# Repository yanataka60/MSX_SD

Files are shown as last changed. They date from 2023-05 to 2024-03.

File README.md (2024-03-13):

# MSXにSD-CARDからロード、セーブ機能

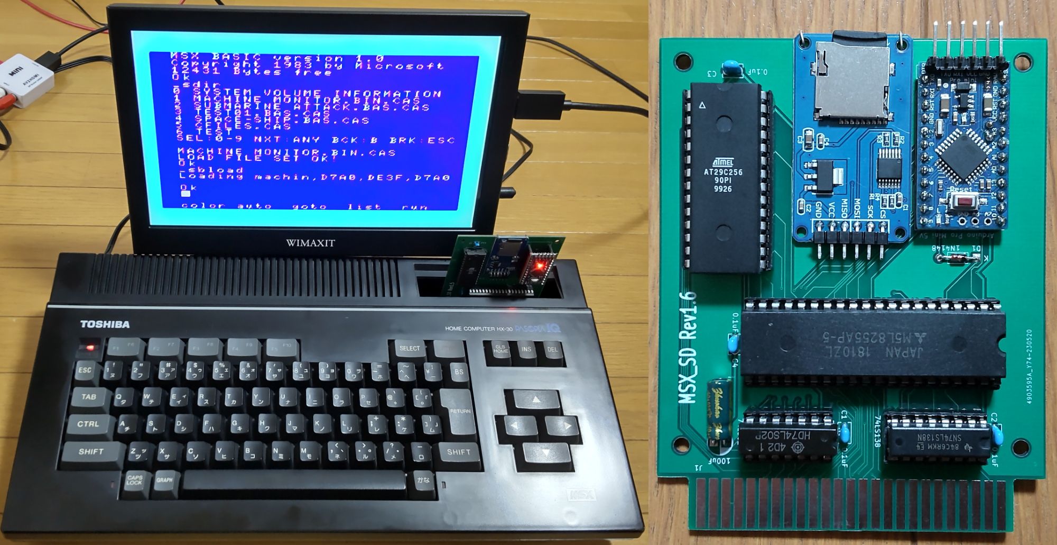
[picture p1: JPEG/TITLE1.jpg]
TITLE

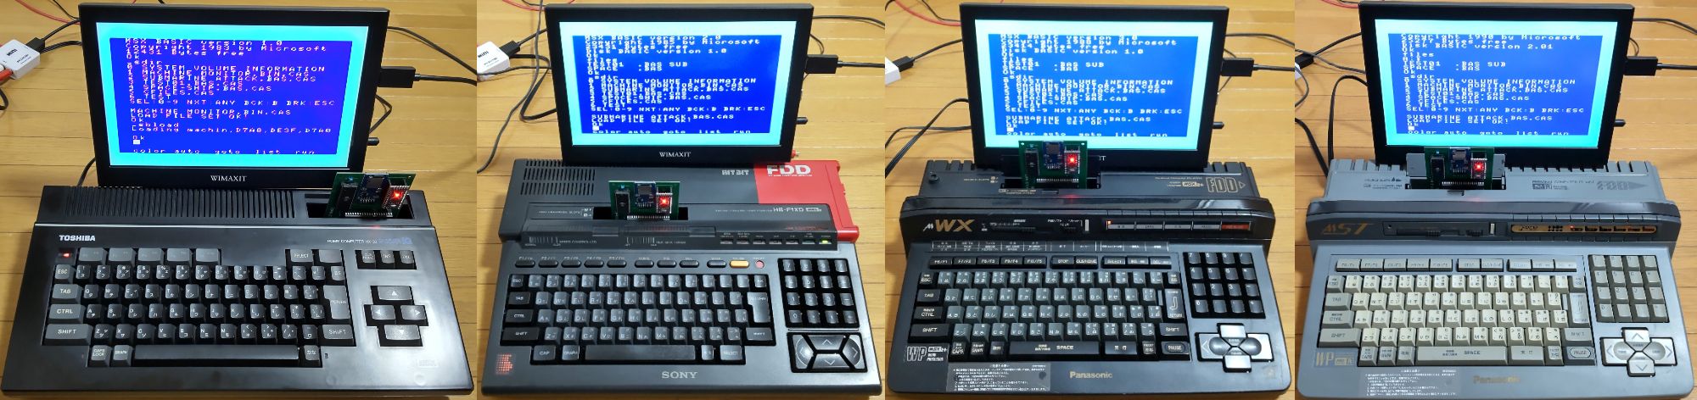
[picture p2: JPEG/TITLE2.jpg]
TITLE2


　MSX、MSX2、MSX2+、MSXturboRでSD-CARDからロード、セーブ機能を実現するものです。

　ROM-BASIC、DISK-BASICのどちらからも使えますが、DISK-BASICのフリーエリアでは動かないカセット用プログラム(ゲーム)もあります。

　FDD内蔵機種でフリーエリアが足りない場合は、SHIFTキーを押しながら電源投入又はリセットしてFDDを切り離してください。

　CMTからの読み込み実行に数分掛かっていたゲームも数十秒で実行できます。

　なお、Arduino、ROMへ書き込むための機器が別途必要となります。

## 対応できないもの
　BASICにSD専用命令を追加することでSD-CARDへのアクセスを実現しています。

　機械語からBIOSをコール、又は独自ルーチンでCMTからLOADするソフトには対応していません。

　雑誌打ち込み系のLOAD、SAVEを想定しています。市販ソフトはLOAD出来ればラッキーくらいに思って活用してください。

## 参考
　市販ソフトをcasファイル化した時に多段ロードではない単純にBASICプログラム、機械語プログラムをロードするものは大丈夫だと思います。

　また、２段ロードでも最初のBASICプログラム中から2段目の機械語プログラムを「BLOAD」で呼び出すものは「CALL SBLOAD」又は「CALL SBLOAD(,R)」に置き換えることで対応できると思います。

## 回路図
　KiCadフォルダ内のMSX_SD.pdfを参照してください。

[回路図](https://github.com/yanataka60/MSX_SD/blob/main/Kicad/MSX_SD.pdf)

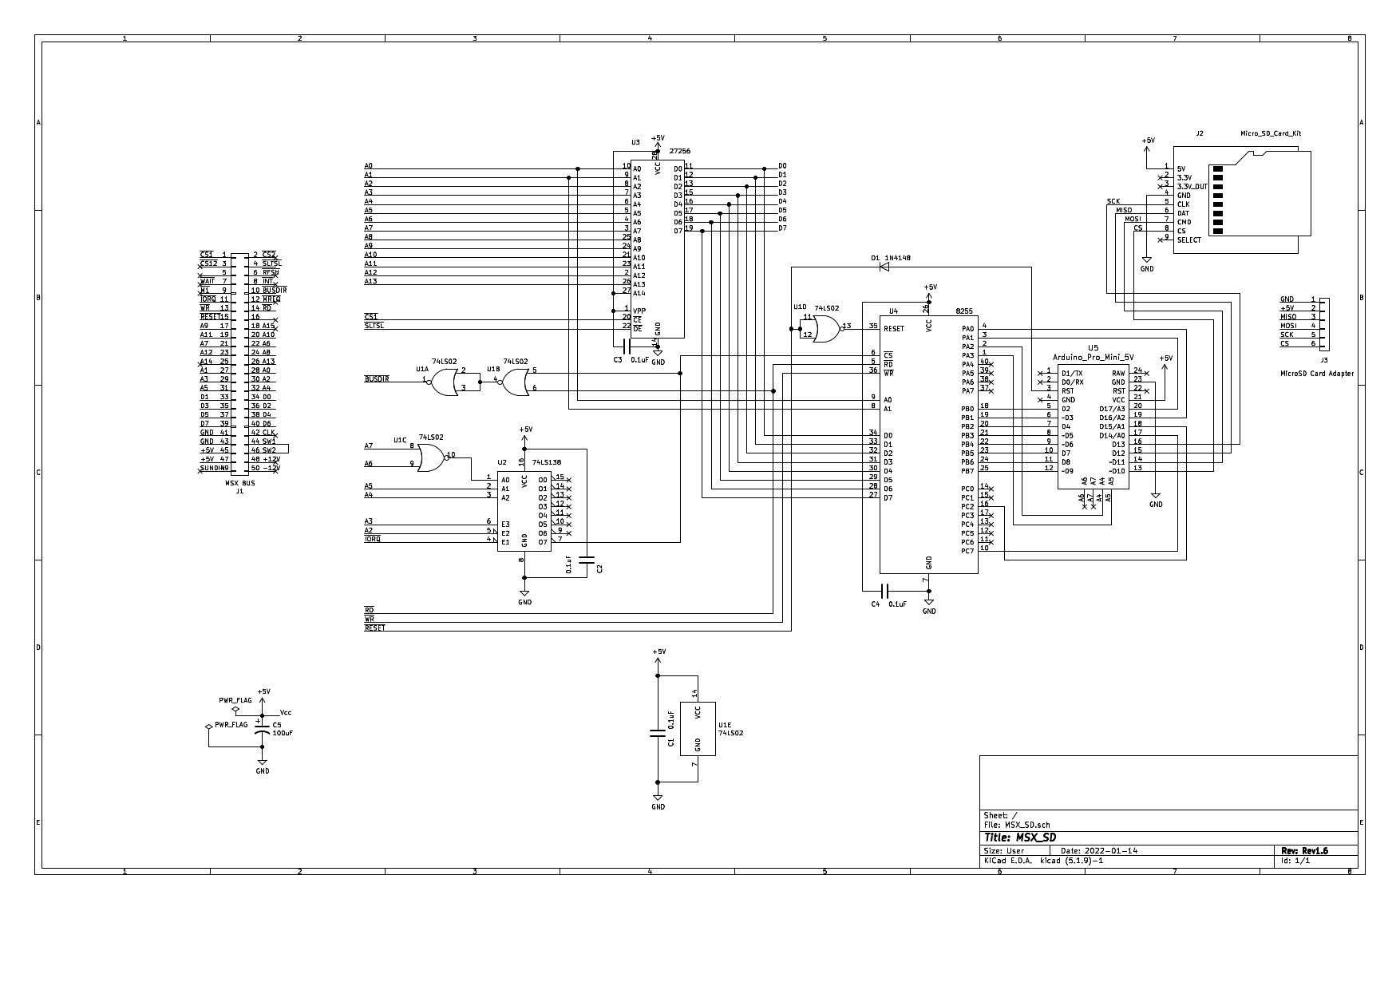
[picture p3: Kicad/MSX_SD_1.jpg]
MSX_SD


## 部品
|番号|品名|数量|備考|
| --- | --- | --- | --- |
||J2、J3のいずれか(注1)|||
|J2|Micro_SD_Card_Kit|1|秋月電子通商 AE-microSD-LLCNV (注2)|
|J3|MicroSD Card Adapter|1|Arduino等に使われる5V電源に対応したもの (注4)|
|D1|1N4148|1||
|U1|74LS02|1||
|U2|74LS138|1||
|U3|27256相当品|1|29C256は可、28C256は不可|
|U4|8255|1||
|U5|Arduino_Pro_Mini_5V|1|Atmega328版を使用 168版は不可。(注3)|
|C1～C4|積層セラミックコンデンサ 0.1uF|4||
|C5|電解コンデンサ 16v100uF|1||
||ピンヘッダ|2Pin分|Arduino_Pro_MiniにはA4、A5用のピンヘッダが付いていないため別途調達が必要です 秋月電子通商 PH-1x40SGなど|
||ピンソケット(任意)|26Pin分|Arduino_Pro_Miniを取り外し可能としたい場合に調達します 秋月電子通商 FHU-1x42SGなど|

　　　注1)J2又はJ3のどちらかを選択して取り付けてください。

　　　注2)秋月電子通商　AE-microSD-LLCNVのJ1ジャンパはショートしてください。

　　　注3)Arduino Pro MiniはA4、A5ピンも使っています。

　　　注4)MicroSD Card Adapterを使う場合

　　　　　J3に取り付けます。

　　　　　MicroSD Card Adapterについているピンヘッダを除去してハンダ付けするのが一番確実ですが、J3の穴にMicroSD Card Adapterをぴったりと押しつけ、裏から多めにハンダを流し込むことでハンダ付けをする方法もあります。なお、この方法の時にはしっかりハンダ付けが出来たかテスターで導通を確認しておいた方が安心です。

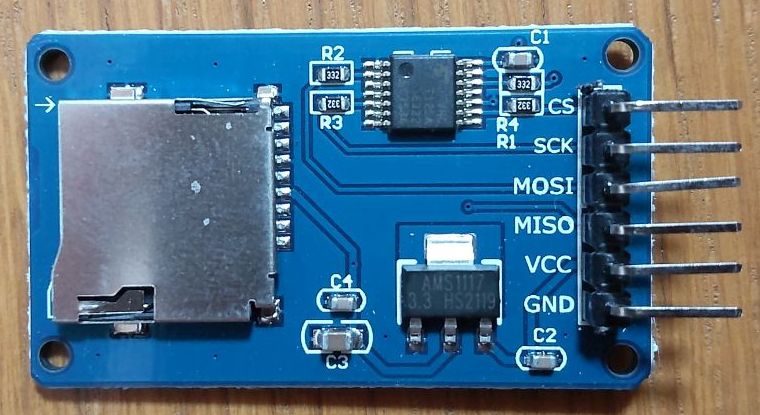
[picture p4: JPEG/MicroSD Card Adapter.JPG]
MicroSD Card Adapter1


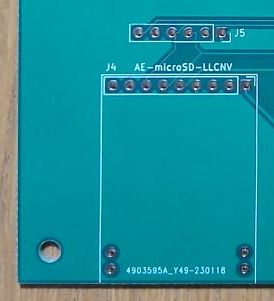
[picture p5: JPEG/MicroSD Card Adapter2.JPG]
MicroSD Card Adapter2


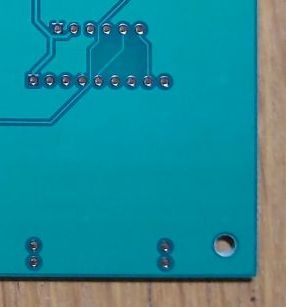
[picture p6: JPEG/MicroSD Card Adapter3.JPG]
MicroSD Card Adapter3


## ROMへの書込み
　Z80フォルダ内のEXT_ROM.binをROMライター(TL866II Plus等)を使って27256又は29C256に書き込みます。

## Arduinoプログラム
　Arduino IDEを使ってArduinoフォルダのMSX_SDフォルダ内MSX_SD.inoを書き込みます。

　SdFatライブラリを使用しているのでArduino IDEメニューのライブラリの管理からライブラリマネージャを立ち上げて「SdFat」をインストールしてください。

　「SdFat」で検索すれば見つかります。「SdFat」と「SdFat - Adafruit Fork」が見つかりますが「SdFat」のほうを使っています。

## 接続
　カートリッジスロットに挿入します。

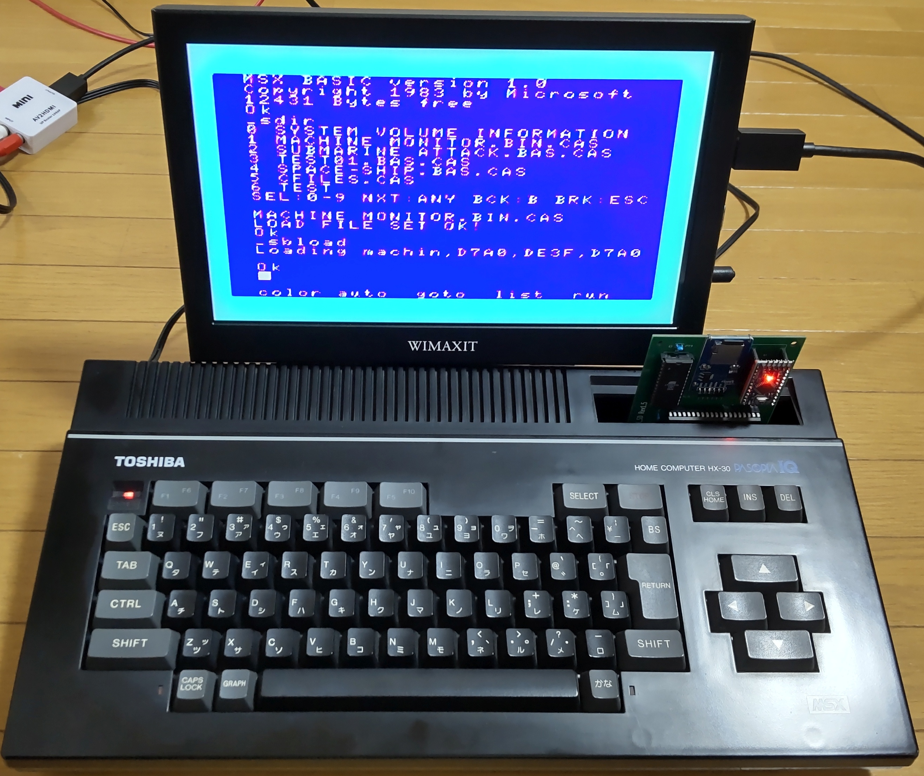
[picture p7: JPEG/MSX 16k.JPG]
cartridge


### SD-CARD
　出来れば8GB以下のSDカードを用意してください。

　ArduinoのSdFatライブラリは、SD規格(最大2GB)、SDHC規格(2GB～32GB)に対応していますが、SDXC規格(32GB～2TB)には対応していません。

　また、SDHC規格のSDカードであっても32GB、16GBは相性により動作しないものがあるようです。

　FAT16又はFAT32が認識できます。NTFSは認識できません。

　ルートに置かれた拡張子が「.CAS」形式ファイルのみ認識できます。(以外のファイル、フォルダも表示されますがLOAD実行の対象になりません)

　ファイル名は拡張子を除いて32文字まで、ただし半角カタカナ、及び一部の記号はArduinoが認識しないので使えません。パソコンでファイル名を付けるときはアルファベット、数字および空白でファイル名をつけてください。

## 使い方
　BASICから以下のコマンドが使えます。

　各コマンドでパラメータを指定する場合には必ず"("をつけてください。"("が無い場合には、MSXの仕様により入力した文字列のすべてがコマンド名として解釈されるため、パラメータを指定しなかったことになります。

### ○CALL SDIR[CR] 又は CALL SDIR("文字列")[CR]
### 【省略形】_SDIR[CR] 又は _SDIR("文字列")[CR]

文字列を指定するときは必ず"("をつけてください。後ろの")"は有っても無くても構いません。

ダブルコーテーションは有っても無くても構いません。

文字列を入力せずにSDIR[CR]のみ入力するとSD-CARDルートディレクトリにあるファイルの一覧を表示します。

文字列を付けて入力すればSD-CARDルートディレクトリにあるその文字列から始まるファイルの一覧を表示します。

10件表示したところで指示待ちになるので打ち切るならESCを入力すると打ち切られ、Bキーで前の10件に戻ります。それ以外のキーで次の10件を表示します。

　行頭に0から9の数字を付加して表示してあるのでSETLしたいファイルの頭についている数字を入力するとSETLコマンドが実行されます。

　表示される順番は、登録順となりファイル名アルファベッド順などのソートした順で表示することはできません。

#### 例)
　　CALL SDIR[CR]

　　CALL SDIR("P")[CR]

　　CALL SDIR(P)[CR]

### ○CALL SETL("DOSファイル名")[CR]
### 【省略形】_SETL("DOSファイル名")[CR]
指定したDOSファイル名のファイルをSD-CARDからLOAD出来るようにセットします。ファイル名の前には必ず"("をつけてください。後ろの")"は有っても無くても構いません。

ダブルコーテーションは有っても無くても構いません。

ファイル名の最後の「.cas」は有っても無くても構いません。

SETLを実行することでカセットテープをセットして読み込む準備をしたことになります。

#### 例)
　　CALL SETL("TEST")[CR]

### ○CALL SLOAD[CR] 又は CALL SLOAD("ファイル名")[CR]
### 【省略形】_SLOAD[CR] 又は _SLOAD("ファイル名")[CR]
CALL SDIR又はCALL SETLでセットしたDOSファイル名に記録されているBASICプログラムをロードします。

ファイル名の前には必ず"("をつけてください。

ダブルコーテーションは有っても無くても構いません。

ファイルデスクリプタ「CAS0:」は不要です。

ASCII形式のBASICプログラムには対応していません。

Rオプションには対応していません。LOAD後実行したい場合にはマルチステートメントでRUNを付け加え、CALL SLOAD:RUN[CR]又はCALL SLOAD("ファイル名"):RUN[CR]などとしてください。

ファイル名が指定されていなければ最初に見つけたBASICプログラムから、ファイル名を指定していれば入力したファイル名から始まるBASICプログラムが見つかるとロードが始まります。

#### 例)
　　CALL SLOAD[CR]

　　CALL SLOAD("TEST")[CR]

カセットテープと同じようにSLOAD命令等で読み込みが行われる度にDOSファイル名で指定したファイルに保存されているプログラムが先頭から一つずつ読み込まれます。

カセットデッキのように巻き戻しは無いので戻りたい時にはもう一度CALL SDIR又はCALL SETLコマンドを実行すれば先頭のプログラム又はデータに戻ります。

### ○CALL SBLOAD[CR]、CALL SBLOAD ("ファイル名")[CR]、CALL SBLOAD(,R)[CR] 又は CALL SBLOAD ("ファイル名",R)[CR]
### 【省略形】_SBLOAD[CR]、_SBLOAD ("ファイル名")[CR]、_SBLOAD(,R)[CR] 又は _SBLOAD ("ファイル名",R)[CR]
CALL SDIR又はCALL SETLでセットしたDOSファイル名に記録されている機械語プログラムをロードします。

ファイル名の前には必ず"("をつけてください。

ダブルコーテーションは有っても無くても構いません。

ファイルデスクリプタ「CAS0:」は不要です。

RオプションをつけることでLOAD後指定された実行開始アドレスから直ちに実行されます。

ファイル名が指定されていなければ最初に見つけた機械語プログラムから、ファイル名を指定していれば入力したファイル名から始まる機械語プログラムが見つかるとロードが始まります。

#### 例)
　　CALL SBLOAD[CR]

　　CALL SBLOAD("TEST")[CR]

　　CALL SBLOAD(,R)[CR]

　　CALL SBLOAD("TEST",R)[CR]

カセットテープと同じようにSBLOAD命令等で読み込みが行われる度にDOSファイル名で指定したファイルに保存されているプログラムが先頭から一つずつ読み込まれます。

カセットデッキのように巻き戻しは無いので戻りたい時にはもう一度CALL SDIR又はCALL SETLコマンドを実行すれば先頭のプログラム又はデータに戻ります。

### ○CALL SETS("DOSファイル名")[CR]
### 【省略形】_SETS("DOSファイル名")[CR]
SD-CARDへのSAVEが指定したDOSファイル名のファイルとなるようにセットします。ファイル名の前には必ず"("をつけてください。後ろの")"は有っても無くても構いません。

ダブルコーテーションは有っても無くても構いません。

ファイル名の最後の「.cas」は有っても無くても構いません。

指定したDOSファイル名のファイルがSD-CARDに存在しない場合は新たに作成され、存在する場合にはそのファイルの続きに追記されます。

SETSを実行することでカセットテープをセットして書き込む準備をしたことになります。

なお、SETSを実行せずにSSAVE、SBSAVEコマンドを実行すると「DEFAULT.cas」というDOSファイル名のファイルに自動的に書き込まれます。

「DEFAULT.cas」でなく好きなDOSファイル名のファイルに書き込みたい時には事前にSETSコマンドを実行してください。

#### 例)
　　CALL SETS("TEST")[CR]

### ○CALL SSAVE("ファイル名")[CR]
### 【省略形】_SSAVE("ファイル名")[CR]
CALL SETSでセットしたDOSファイル名のファイルにBASICプログラムをSAVEします。

ファイル名の前には必ず"("をつけてください。

ダブルコーテーションで必ず括る必要はありませんが、MSXの仕様上ダブルコーテーションで括った場合には文字列として判断され小文字はそのまま小文字ですが、括らなかった場合には変数名と判断され小文字はすべて大文字に変換されます。

ファイルデスクリプタ「CAS0:」は不要です。

ファイル名は省略できません。6文字以内でファイル名を指定してください。

#### 例)
　　CALL SSAVE("test")[CR]　　　:ファイル名testとしてSAVEされます。

　　CALL SSAVE("TEST")[CR]　　　:ファイル名TESTとしてSAVEされます。

　　CALL SSAVE(test)[CR]　　　　:ファイル名TESTとしてSAVEされます。

　　CALL SSAVE(TEST)[CR]　　　　:ファイル名TESTとしてSAVEされます。

カセットテープと同じようにSSAVE命令等で書き込みが行われる度にDOSファイル名で指定したファイルにBASICプログラムを追記します。

### ○CALL SBSAVE("ファイル名",開始アドレス,終了アドレス,実行開始アドレス)[CR]
### 【省略形】_SBSAVE("ファイル名",開始アドレス,終了アドレス,実行開始アドレス)[CR]
CALL SETSでセットしたDOSファイル名のファイルに開始アドレスから終了アドレスまでのメモリ上に置かれている機械語プログラムをSAVEします。

ファイル名の前には必ず"("をつけてください。

ダブルコーテーションで必ず括る必要はありませんが、MSXの仕様上ダブルコーテーションで括った場合には文字列として判断され小文字はそのまま小文字ですが、括らなかった場合には変数名と判断され小文字はすべて大文字に変換されます。

ファイルデスクリプタ「CAS0:」は不要です。

ファイル名、開始アドレス、終了アドレス、実行開始アドレスは16進数(&H)または32767までの10進数で指定してください。省略できません。

6文字以内でファイル名を指定してください。

#### 例)
　　CALL SBSAVE("TEST",&HA000,&HAFFF,&HA000)[CR]

カセットテープと同じようにSBSAVE命令等で書き込みが行われる度にDOSファイル名で指定したファイルに機械語プログラムを追記します。

### ○CALL DUMP[CR] 又は CALL DUMP(開始アドレス)[CR]
### 【省略形】_DUMP[CR] 又は _DUMP(開始アドレス)[CR]
メモリの内容を開始アドレスから128Byte分表示します。

開始アドレスを指定する場合には"("をつけ、16進数(&H)または32767までの10進数で指定してください。

開始アドレスを省略した場合には直前にCALL SBLOADされた機械語プログラムの実行開始アドレス又はCALL DUMPで表示された続きを表示します。

#### 例)
　　CALL DUMP(&HA000)[CR]　　　:アドレスA000からメモリ内容を表示します。

　　直後にCALL DUMP[CR]　　　　:直前に表示したメモリ内容(&HA000～&HA07F)の続きとして&HA080～&HA0FFを表示します。

　　CALL SBLOADを実行した直後にCALL DUMP[CR]　　　　:直前にLOADされた機械語プログラムの実行開始アドレスからメモリ内容を表示します。

### ○CALL EDIT[CR] 又は CALL EDIT(開始アドレス)[CR]
### 【省略形】_EDIT[CR] 又は _EDIT(開始アドレス)[CR]
開始アドレスが表示されるのでその後ろに16進数を入力し最後に[CR]を押すことでメモリにデータを書き込むことができます。

開始アドレスを指定する場合には"("をつけ、16進数(&H)または32767までの10進数で指定してください。

開始アドレスを省略した場合には直前にCALL SBLOADされた機械語プログラムの実行開始アドレス又はCALL DUMPで表示された続きのアドレスが書き込み開始アドレスとなります。

#### 例)
　　CALL EDIT(&HA000)[CR]　　　:とすると改行してA000が表示されるので16進数を入力後[CR]を押す。

　　A000 12 34 56 78 90[CR]　　:アドレスA000から 12 34 56 78 90の5Byteが書き込まれ、次のアドレスA005が表示される。

　　A005 [CR]　　　　　　　　　:終了したい時はアドレス表示の後に[CR]だけ押せば終了となる。

### ○CALL GOTO[CR] 又は CALL GOTO(実行開始アドレス)[CR]
### 【省略形】_GOTO[CR] 又は _GOTO(実行開始アドレス)[CR]
実行開始アドレスの機械語プログラムを呼び出します。

開始アドレスを指定する場合には"("をつけ、16進数(&H)または32767までの10進数で指定してください。

開始アドレスを省略した場合には直前にCALL SBLOADされた機械語プログラムの実行開始アドレス又はCALL DUMPで表示された続きが実行開始アドレスとなります。

#### 例)
　　CALL GOTO(&HA000)[CR]　　　:アドレスA000からの機械語プログラムを呼び出します。

　　CALL SBLOADを実行した直後にCALL GOTO[CR]　　　:直前にLOADされた機械語プログラムの実行開始アドレスの機械語プログラムを呼び出します。CALL SBLOAD(,R)と同等の動作となります。

### 操作上の注意
　~~「SD-CARD INITIALIZE ERROR」と表示されたときは、SD-CARDが挿入されているか確認し、SD-CARDを挿入して再度実行してください。~~

　~~SD-CARDにアクセスしていない時に電源が入ったままで SD-CARDを抜いた後、再挿入しても動作します。もし、「SD-CARD INITIALIZE ERROR」となる場合には本体の電源を入れ直してください。~~

　(2024.3.13) SD-CARDにアクセスしていない時に電源が入ったままでSD-CARDを抜くと再度SD-CARDを挿入してもSD-CARDにアクセスできない問題を解消しました。(Arduinoを最新版に書き換えてください)

　再度SD-CARDを挿入した後、_SDIR、_SETL、_SETS、_SSAVE、_SBSAVE等でSD-CARDに3回ほどアクセスすれば復旧します。

　_SLOAD、_SBLOADでも復旧しますが、_SDIR、_SETL等DOSファイル名をセットするところから復旧させることをお勧めします。

## 機械語多段ロードでBIOSをコールしているプログラムへの対応【テストバージョン】
　「MSX快速マシン語ゲーム集」に掲載されている「ジグソーセット」は、選んだ絵のデータを機械語のサブプログラムからBIOSのCMTアクセスルーチンをコールしてロードする仕様になっています。

　CALL文で拡張したSDアクセス用のコマンドではBIOSを直接コールするアプリケーションには対応できないのでアプリケーション中のCMT用BIOSコール部分を書き換えてSDアクセスする実験をしてみました。

　今回は、BIOSのCMTロード関連のみパッチを当てています。BIOSのCMTセーブ関連は未対応です。

　同様に、機械語多段ロードでBIOSをコールしているゲーム等ももしかしたら起動できるかもしれません。

#### 注意
　アプリケーションからSDアクセスルーチンをコールするためにSDアクセスルーチンをFDのワークエリアにコピーしています。機械語多段ロードでBIOSをコールしているプログラムをテストするときは必ずFDを切り離して起動してください。

　機械語多段ロードでBIOSをコールしているプログラムをロード実行しない限りFDとは共存します。

　なお、機械語多段ロードのアプリケーションでもBIOSのCMT関連ルーチンをコールせず、独自の特殊フォーマットでCMTから読み込んでいるものは対処しようがないので読み込めません。

### ROMへの書込み
　BIOS CALL REPLACE TESTフォルダ内Z80フォルダ内のEXT_ROM.binをROMライター(TL866II Plus等)を使って27256又は29C256に書き込みます。

　同ファイルにあるEXT_ROM2.sはアセンブル後のコードをEXT_ROM.binに含めてあります。

　テスト用のプログラムを付け加えた以外は通常版と同じですのでテストを止めたとしても元に戻す必要はありません。

### Arduinoプログラム
　Arduino IDEを使ってBIOS CALL REPLACE TESTフォルダ内ArduinoフォルダのMSX_SDフォルダ内MSX_SD.inoを書き込みます。

　テスト用のプログラムを付け加えた以外は通常版と同じですのでテストを止めたとしても元に戻す必要はありません。

### アプリケーションパッチあてWindows用ツール
　デスクトップ等適当な場所にBIOS CALL REPLACE TESTフォルダ内の「CAS2SD_CHECK.exe」をコピーしてダブルクリックで起動させてください。

　次にSD用パッチを当てたいCASファイルをCAS2SD_CHECKにドラッグアンドドロップしてください。

　ドロップされたアプリケーションにBIOSのCMT関連ルーチンを呼び出していると思われるコードが発見された場合は、元のCASファイルと同じフォルダに元のCASファイルのファイルネームに「_SD」を付加したCASファイルと変更箇所を保存したTXTファイルを作成します。

　ドロップされたアプリケーションにBIOSのCMT関連ルーチンを呼び出していると思われるコードが無い場合には、何も作成されません。

例)

　「JIGSAW SET.cas」をドラッグアンドドロップ

　　JIGSAW SET_SD.cas、JIGSAW SET_SD.txtが作成される。

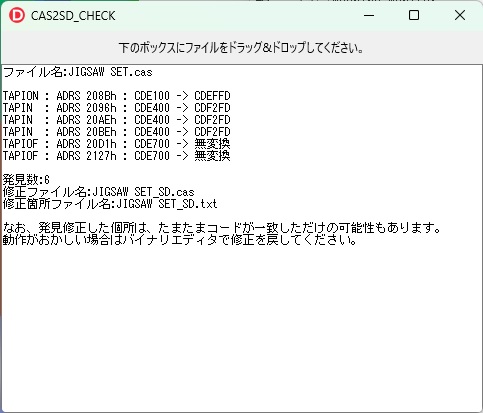
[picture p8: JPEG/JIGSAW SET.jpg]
JIGSAW SET


### レトロPC用ビットマップコンバーター TINY Bitmap Converterで生成された画像のロード
　TINY野郎さんのTINY Bitmap Converterで作られたCASファイルをMSX_SDで読み込むためのパッチ当てプログラムを作ってみました。

　デスクトップ等適当な場所にBIOS CALL REPLACE TESTフォルダ内の「TINYBMPCONV_MSX_SD_CONV.exe」をコピーしてダブルクリックで起動させてください。

　次にSD用パッチを当てたいCASファイルをTINYBMPCONV_MSX_SD_CONVにドラッグアンドドロップしてください。

　ドロップされた元のCASファイルと同じフォルダに元のCASファイルのファイルネームに「_SD」を付加したCASファイルを作成します。

　TINY Bitmap ConverterでMSX用に生成されたCASファイル以外をドロップしても多分何も作成されません。

例)

　「GAZOU.cas」をドラッグアンドドロップ

　　GAZOU_SD.casが作成される。

#### やっていること
　TINY Bitmap ConverterでMSX用に生成されたCASファイルはBASICで書かれたローダーの後ろに画像データがあります。

　BASICで書かれたローダーはDATA文で読み込んだ機械語をメモリに書き込んで実行していますが、DATA文なのでCAS2SD_CHECKを使ってもMSX_SD用にパッチ当てが出来ません。

　そこでDATA文に書かれたCMTルーチンコール用の機械語をSD用に置き換えています。

## 謝辞
　基板の作成に当たり以下のデータを使わせていただきました。ありがとうございます。

　Arduino Pro Mini

　　https://github.com/g200kg/kicad-lib-arduino

　AE-microSD-LLCNV

　　https://github.com/kuninet/PC-8001-SD-8kRAM

　にが様に多大なるご助言を頂きました。ありがとうございます。

## 追記
2023.5.22 キースキャンルーチンにWAITを追加

2023.5.28 _SBLOAD(,R)、_GOTOコマンドからのリターン時にHLレジスタを復帰していなかったバグを修正

　　　　_GOTOコマンドで実行開始アドレス省略時にマルチステートメントに対応していなかったバグを修正

　　　　マシン語自動実行用ワークエリア調整

2023.6.3 機械語多段ロードでBIOSをコールしているプログラムへの対応【テストバージョン】をアップした。

2023.8.2 ROMへの書込みにアドレス0000Hからで済むよう変更した。

2024.1.15 SDカードは8GB以下が望ましいことを追記。

2024.2.4 TINY Bitmap Converter用パッチ当てプログラムを作成。

2024.3.13 電源が入ったままでSD-CARDを抜くと再度SD-CARDを挿入してもSD-CARDにアクセスできない問題を解消した。

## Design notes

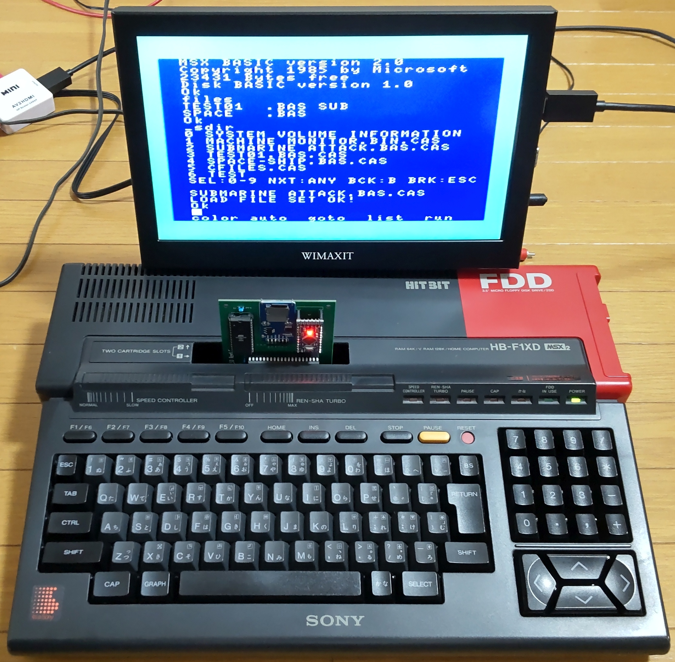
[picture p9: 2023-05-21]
JPEG/MSX2.JPG

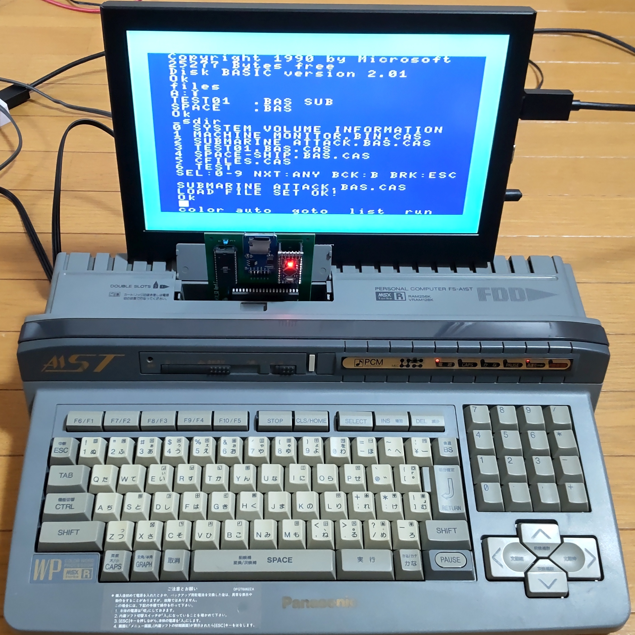
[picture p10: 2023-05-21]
JPEG/MSXturboR.JPG

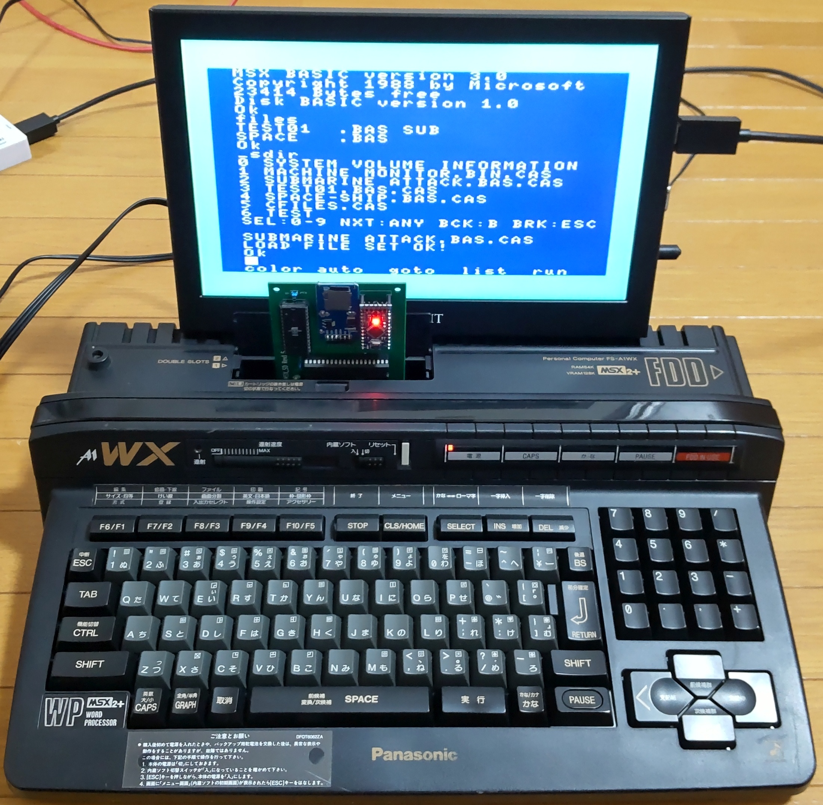
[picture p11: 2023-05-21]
JPEG/MSX2+.JPG

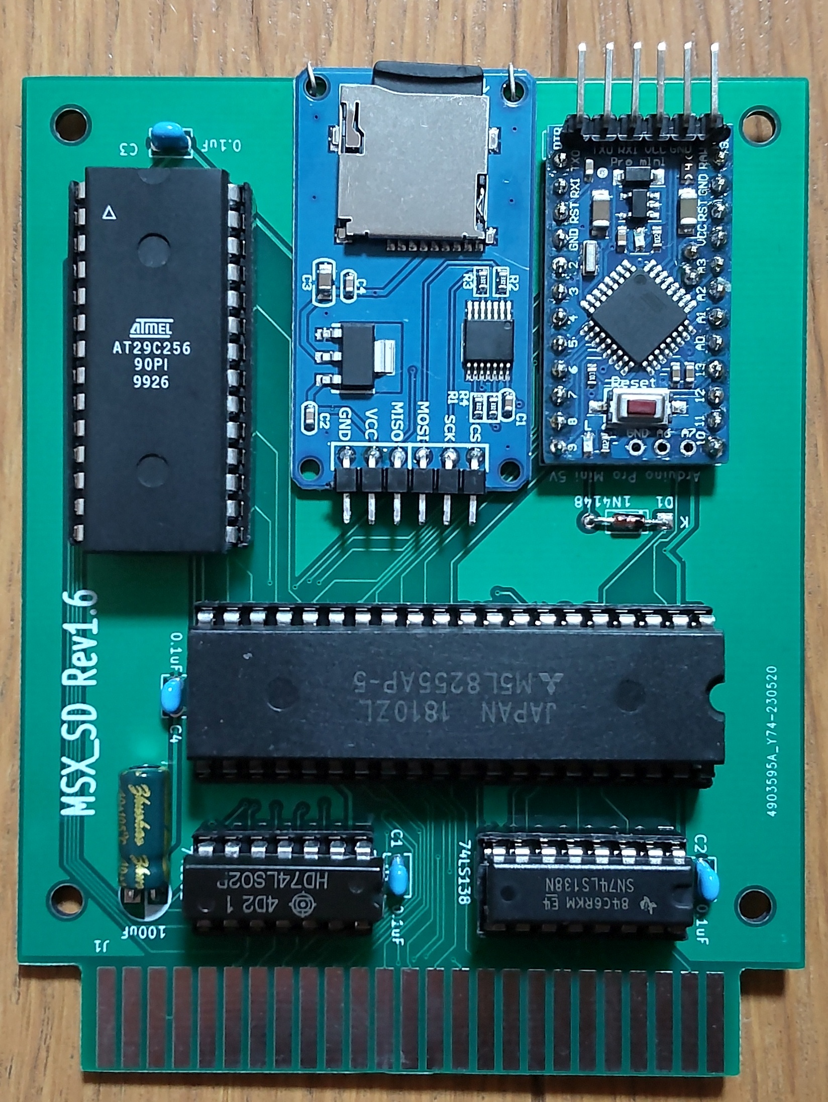
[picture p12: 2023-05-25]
JPEG/MSX_SD.JPG

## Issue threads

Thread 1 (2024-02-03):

F4 Error

atssada, 2024-02-03:
素晴らしい作品を公開していただきありがとうございます！

まねで楽しくことしかできないものとして、恥ずかしながら質問させていただきます。

Call sdirコマンドで

F4 Error

が出ますが、SDカードの問題ですかね？
3種類のSDカードをFAT32でフォーマットして、ルートディレクトにBatman.casを一つだけ置き、試しましたが、どれもF4 Errorでした。

yanataka60, 2024-02-03:
F4 Errorは、MSXがArduinoへ送るコマンドがArduinoにとって想定外であることを表しています。
ひとつ考えられるケースとしてArduinoのA4、A5ピンを配線していないのではないでしょうか。
確認してみてください。

2024年2月3日(土) 18:21 Jinyong Kim ***@***.***>:

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

atssada, 2024-02-05:
ご親切な説明ありがとうございます！

無事解決できました！ mm

yanataka60, 2024-02-05:
解決できて良かったです。

2024年2月6日(火) 8:18 Jinyong Kim ***@***.***>:

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

Closed 2024-02-05.

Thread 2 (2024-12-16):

_sload and _sbload feedback not find file

hpx1984, 2024-12-16:
Dear Sir Yanataka60

your MSX SD is a very great project and i built one of it

now my unit can run "_sdir" and can see all “xxx.cas“ROM file what i copy to 4G TF card and also can run "_setl" to feedback "LOAD FILE SET OK!"
and then run“_sload" and "_sbload"get "not find file"
My MSX model is CASIO MX-10
Now i don't know how to run .cas ROM ,could you help me?

yanataka60, 2024-12-16:
First of all, are you sure that the cas file is a file that can be read and executed by MSX Emulator?

hpx1984, 2024-12-16:
yes，sure，it could read and executed by MSX Emulator(on line)

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

yanataka60, 2024-12-16:
As stated in README.md, access to SD-CARD is achieved by adding SD-specific instructions to BASIC, so not all commercial software can support SD-CARD.

「雑誌打ち込み系のLOAD、SAVEを想定しています。市販ソフトはLOAD出来ればラッキーくらいに思って活用してください。」

With that assumption understood, please try the following modifications.
Modify the two BASIC programs included in “007 - A View to a Kill.cas”.

AVTAK1.bas
100 _SLOAD "AVTAK2"

AVTAK2.bas
20 _SBLOAD"LODCOD"
180 _SBLOAD"MINE"
210 _SBLOAD"HALL"

In my environment, the following further modifications were necessary.

AVTAK2.bas
120 REM
170 REM
200 REM

hpx1984, 2024-12-16:
many thx your explain , i will try to study how to modify cas file

btw do you have any cas file that good to read and executed from MSX-SD can share? or do you know which Web can download these file  ?
im so sorry to trouble you again and again
many thx your kindly support

hpx1984, 2024-12-16:
i try to do modify one cas file but got same result
attached the cas file that modified from me， please help to check if any error
[007a2.zip](https://github.com/user-attachments/files/18148143/007a2.zip)

yanataka60, 2024-12-16:
Numerous games are available for MSX as well as many 8-bit PCs at this site published by いぬふと.
http://inufuto.web.fc2.com/8bit/

yanataka60, 2024-12-16:
The cas file included in the attached file has AVTAK1.BAS and AVTAK2.BAS in the wrong order and the contents of AVTAK2.BAS are corrupted.
We recommend that you start again with the correct cas file.
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

hpx1984, 2024-12-22:
Thx Sir Yanataka60

i trial to extracts CAS file(used MCP TOOL) and got "AVTAK1.BAS and AVTAK2.BAS" and then did modify according your Guide,  and then re-packing these files to CAS ,
as your information above i think might this tool can't support for re-packing to CAS file
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

now i did downloading some CAS files from above line as you shared ,but still can't Load from MSX-SD
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

yanataka60, 2024-12-22:
You do not understand cas files.
A cas file is an image of a cassette tape, and the program recorded in it does not necessarily have the same name as the cas file.
For example, the program contained in battlot.cas is BATTLO.BIN.
If you follow the instructions on how to run BATTLOT,「テープ版:(DISK BASICを無効にしてください)bload "cas:",r」, you should instruct as follows.

_setl("battlot.cas")
_sbload(,R)

I wonder if “007 - A View to a Kill.cas” makes the same mistake.
I would have instructed the following.

_setl("007 - A View to a Kill.cas")
_sload
run

I'll give you an example of a tool that can edit cas files, but I can't take care of how to use it, so you'll have to do it yourself.
https://bugfire2009.ojaru.jp/download.html#dleditor

hpx1984, 2025-01-12:
HI Sir Yanataka60

many thx your help
now i could run the cas file that download from the link you shared :http://inufuto.web.fc2.com/8bit/
but still can't run the game cas as modified the BAS file

this is what i did:
1.for easy to input command in MSX i shorted the file name to "007aX-number"
the 007A.cas is the original CAS file
the 007a3 and a4 was modify the BAS file by the Editor that tool got from above link you shared.
2. open the original cas file by Editor and then double click bas file and then modify the notepad and save
3. write cas

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

[007 CAS.zip](https://github.com/user-attachments/files/18387965/007.CAS.zip)

and i found so many CAS files as this one that only one BAS file and i try to modify it to _sbload"bin file name" but can't run succeed
[CAS.zip](https://github.com/user-attachments/files/18388021/CAS.zip)

yanataka60, 2025-01-12:
The modification of 007A3.cas is correct, but MSX_SD does not support BASIC programs in ASCII format, so do not save in ASCII format.
As I said at the beginning of this article, please “think of commercial software as a lucky thing if you can LOAD it and make use of it.
I don't want to talk about commercial software, so please finish this topic.

hpx1984, 2025-01-12:
Okay , understood
many thx your help Sir

Closed 2025-01-12.

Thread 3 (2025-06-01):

Arduino_Pro_Mini vs Arduino_Pro_Micro

Pax-nl, 2025-06-01:
Hi,

Is it possible to use an Arduino_Pro_Micro? If so could you explain what to change in the code (if needed).

Regards, PaxNL.

yanataka60, 2025-06-02:
I believe the Arduino Pro Mini does not have an A4 or A5 and cannot be used.

I believe Gemini's proposed replacement for A4 points to the same pin.
#define PA2PIN (A9) // Pro Mini A4 (D18) -> Pro Micro A9 (D12)
#define PB7PIN (9) // D9 - OK

Pax-nl, 2025-06-02:
Ok, thank you, I will give up, ordered a Mini..

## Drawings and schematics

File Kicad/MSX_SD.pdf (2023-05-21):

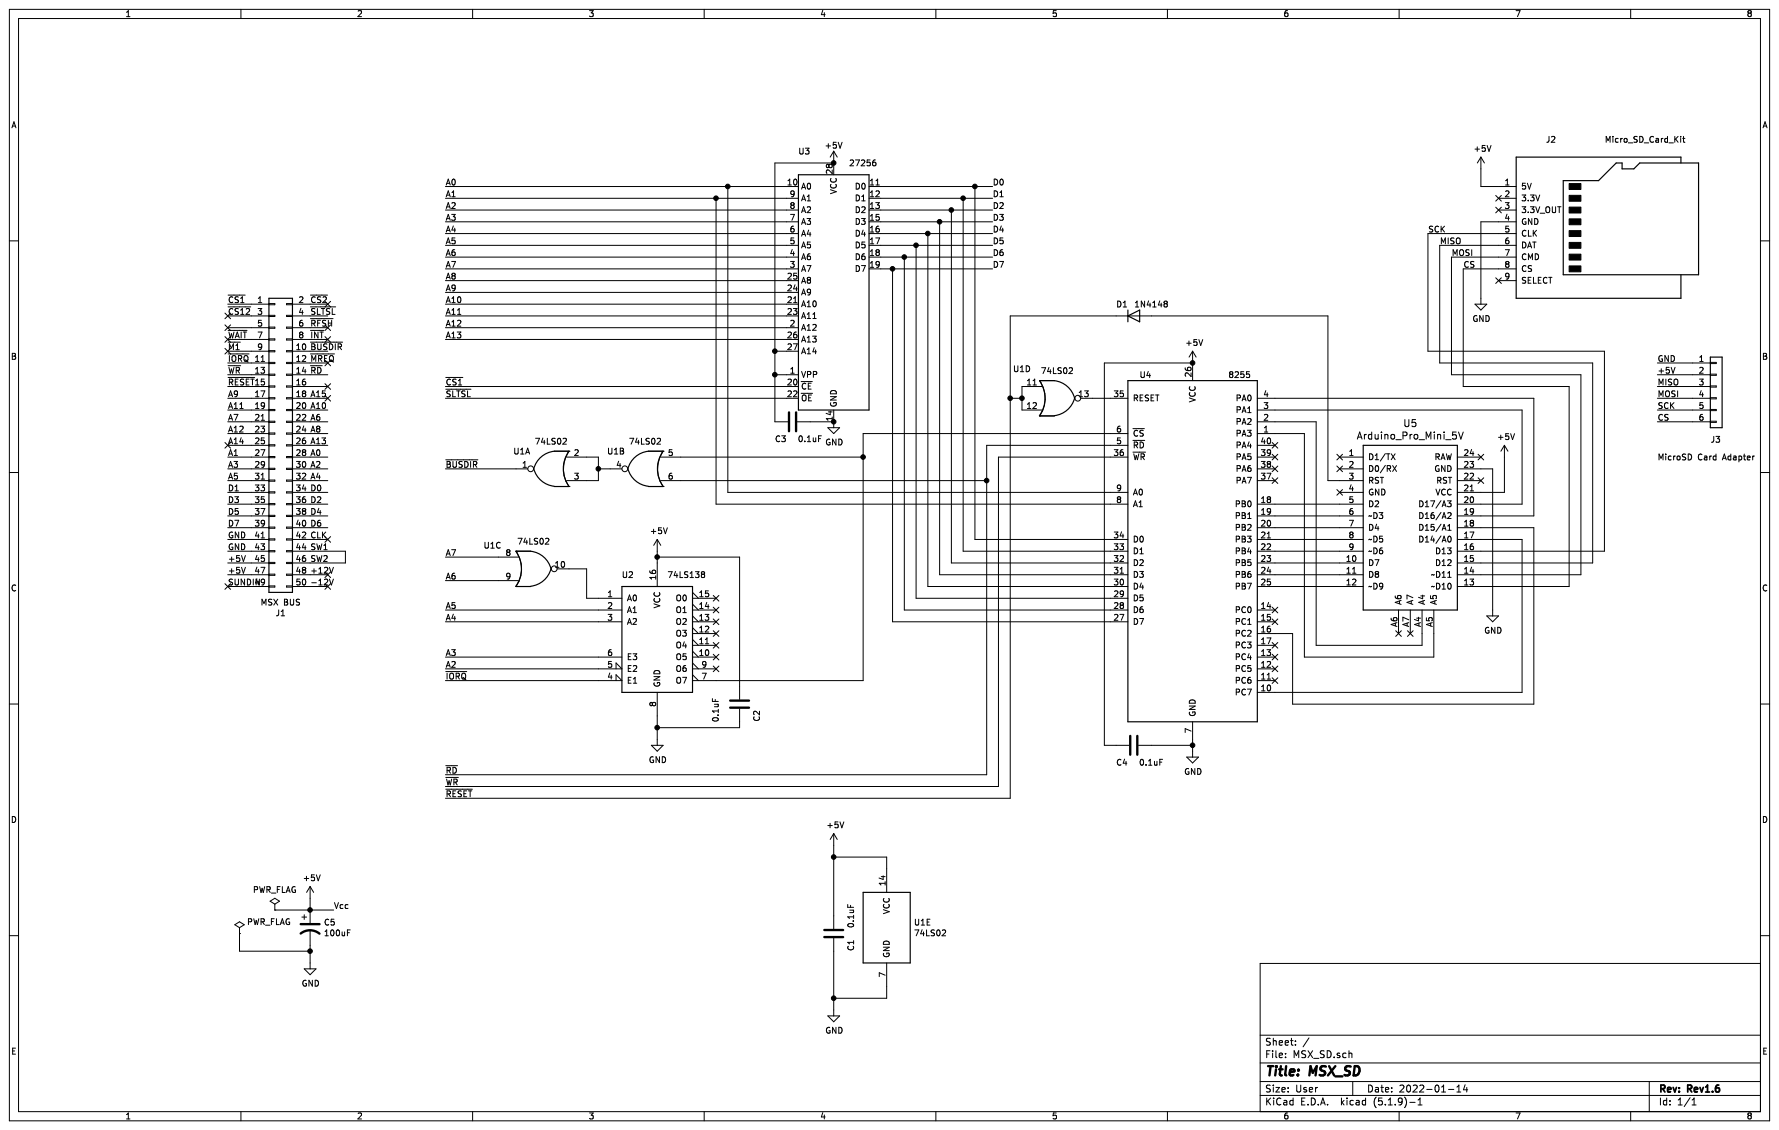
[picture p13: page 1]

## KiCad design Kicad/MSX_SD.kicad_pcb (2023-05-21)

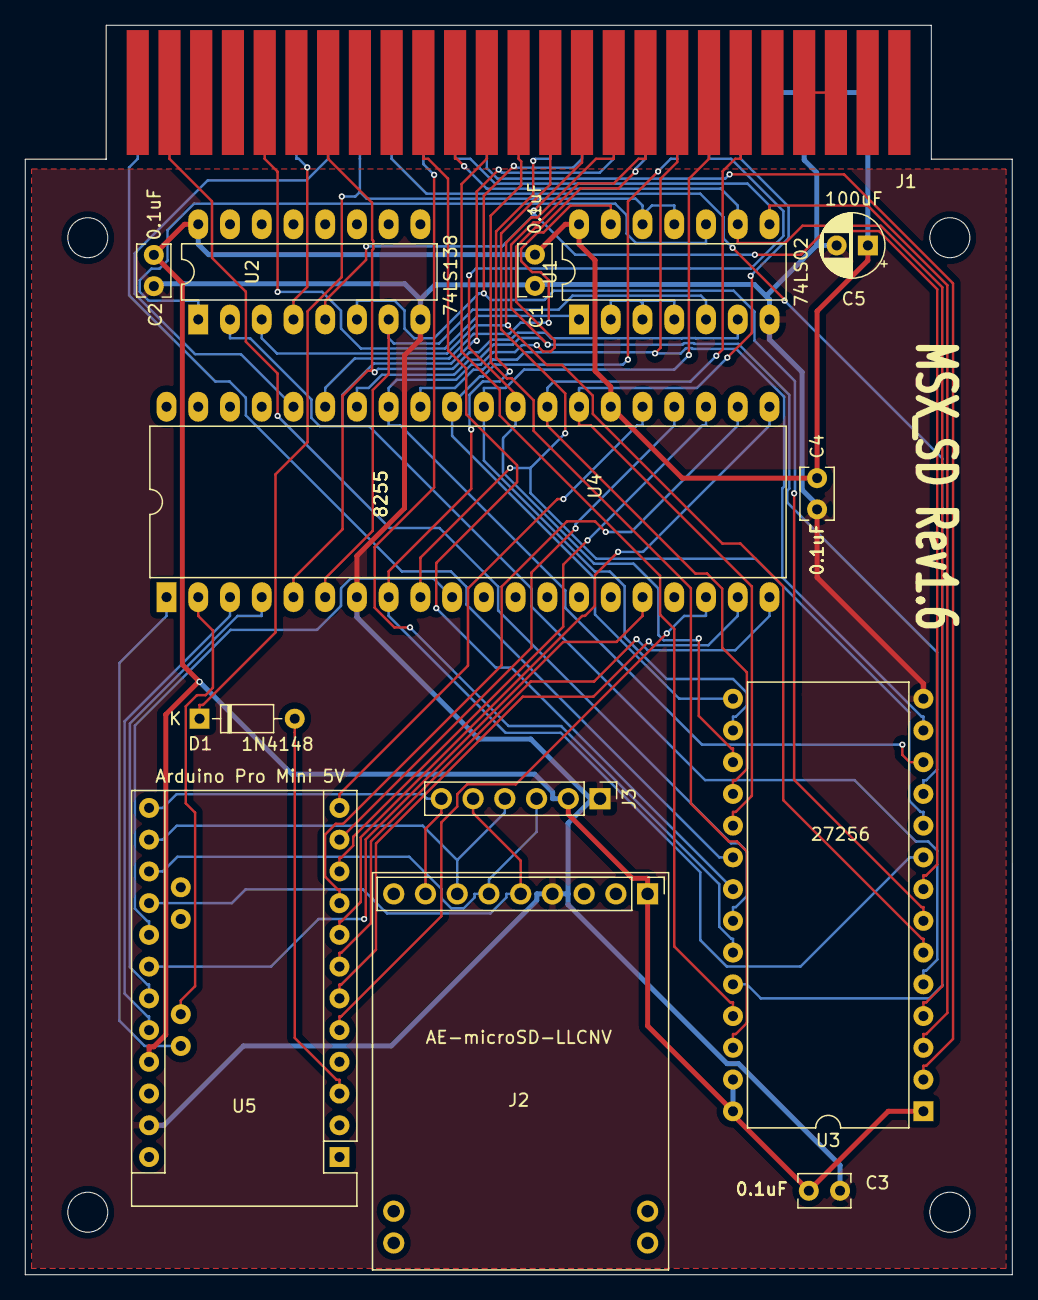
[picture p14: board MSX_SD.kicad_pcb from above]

Board: 2 copper layers, 79.0 x 100.0 mm, 18 parts (0 on the bottom side), 55 nets.

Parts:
C1, C2, C3, C4: 0.1uF; C_Rect_L4.0mm_W2.5mm_P2.50mm
C5: 100uF; CP_Radial_D5.0mm_P2.50mm
D1: 1N4148; D_DO-35_SOD27_P7.62mm_Horizontal
J1: MSX BUS; BUS_50Pin
J2: Micro_SD_Card_Kit; AE-microSD-LLCNV
J3: MicroSD Card Adapter; PinHeader_1x06_P2.54mm_Vertical
MH1, MH2, MH3, MH4: MountingHole_3.2mm_M3
U1: 74LS02; DIP-14_W7.62mm_LongPads
U2: 74LS138; DIP-16_W7.62mm_LongPads
U3: 27256; DIP-28_W15.24mm
U4: 8255; DIP-40_W15.24mm_LongPads
U5: Arduino_Pro_Mini_5V; Arduino_Pro_Mini

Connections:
+5V: C1.2, C2.2, C3.1, C4.1, C5.1, J1.45, J1.47, J2.1, J3.2, U1.14, U2.16, U3.1, U3.27, U3.28, U4.26, U5.21
/A0: J1.28, U3.10, U4.9
/A1: J1.27, U3.9, U4.8
/A2: J1.30, U2.5, U3.8
/A3: J1.29, U2.6, U3.7
/A4: J1.32, U2.3, U3.6
/A5: J1.31, U2.2, U3.5
/A6: J1.22, U1.9, U3.4
/A7: J1.21, U1.8, U3.3
/A8: J1.24, U3.25
/A9: J1.17, U3.24
/A10: J1.20, U3.21
/A11: J1.19, U3.23
/A12: J1.23, U3.2
/A13: J1.26, U3.26
/CS: J2.8, J3.6, U5.13
/D0: J1.34, U3.11, U4.34
/D1: J1.33, U3.12, U4.33
/D2: J1.36, U3.13, U4.32
/D3: J1.35, U3.15, U4.31
/D4: J1.38, U3.16, U4.30
/D5: J1.37, U3.17, U4.29
/D6: J1.40, U3.18, U4.28
/D7: J1.39, U3.19, U4.27
/MISO: J2.6, J3.3, U5.15
/MOSI: J2.7, J3.4, U5.14
/SCK: J2.5, J3.5, U5.16
/SW1: J1.44, J1.46
/~BUSDIR: J1.10, U1.1
/~CS1: J1.1, U3.20
/~IORQ: J1.11, U2.4
/~RD: J1.14, U1.6, U4.5
/~RESET: D1.1, J1.15, U1.11, U1.12
/~SLTSL: J1.4, U3.22
/~WR: J1.13, U4.36
GND: C1.1, C2.1, C3.2, C4.2, C5.2, J1.41, J1.43, J2.4, J3.1, U1.7, U2.8, U3.14, U4.7, U5.23
unnamed: D1.2, U5.3
unnamed: U1.2, U1.3, U1.4
unnamed: U1.5, U2.7, U4.6
unnamed: U1.10, U2.1
unnamed: U1.13, U4.35
unnamed: U4.1, U5.A5
unnamed: U4.2, U5.A4
unnamed: U4.3, U5.20
unnamed: U4.4, U5.19
unnamed: U4.10, U5.17
unnamed: U4.16, U5.18
unnamed: U4.18, U5.5
unnamed: U4.19, U5.6
unnamed: U4.20, U5.7
unnamed: U4.21, U5.8
unnamed: U4.22, U5.9
unnamed: U4.23, U5.10
unnamed: U4.24, U5.11
unnamed: U4.25, U5.12

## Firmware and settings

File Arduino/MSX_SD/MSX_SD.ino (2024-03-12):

//2024. 3.13 sd-card再挿入時の初期化処理を追加
//
#include "SdFat.h"
#include <SPI.h>
SdFat SD;
unsigned long r_count=0;
unsigned long f_length=0;
char m_name[40];
char f_name[40];
char w_name[40];
char c_name[40];
char sdir[10][40];
File file_r,file_w;
unsigned int s_adrs,e_adrs,g_adrs,s_adrs1,s_adrs2;
boolean eflg;

#define CABLESELECTPIN  (10)
#define CHKPIN          (15)
#define PB0PIN          (2)
#define PB1PIN          (3)
#define PB2PIN          (4)
#define PB3PIN          (5)
#define PB4PIN          (6)
#define PB5PIN          (7)
#define PB6PIN          (8)
#define PB7PIN          (9)
#define FLGPIN          (14)
#define PA0PIN          (16)
#define PA1PIN          (17)
#define PA2PIN          (18)
#define PA3PIN          (19)
// ファイル名は、ロングファイルネーム形式対応

void sdinit(void){
  // SD初期化
  if( !SD.begin(CABLESELECTPIN,8) )
  {
////    Serial.println("Failed : SD.begin");
    eflg = true;
  } else {
////    Serial.println("OK : SD.begin");
    eflg = false;
  }
////    Serial.println("START");
}

void setup(){
////    Serial.begin(9600);
// CS=pin10
// pin10 output

  pinMode(CABLESELECTPIN,OUTPUT);
  pinMode( CHKPIN,INPUT);  //CHK
  pinMode( PB0PIN,OUTPUT); //送信データ
  pinMode( PB1PIN,OUTPUT); //送信データ
  pinMode( PB2PIN,OUTPUT); //送信データ
  pinMode( PB3PIN,OUTPUT); //送信データ
  pinMode( PB4PIN,OUTPUT); //送信データ
  pinMode( PB5PIN,OUTPUT); //送信データ
  pinMode( PB6PIN,OUTPUT); //送信データ
  pinMode( PB7PIN,OUTPUT); //送信データ
  pinMode( FLGPIN,OUTPUT); //FLG

  pinMode( PA0PIN,INPUT_PULLUP); //受信データ
  pinMode( PA1PIN,INPUT_PULLUP); //受信データ
  pinMode( PA2PIN,INPUT_PULLUP); //受信データ
  pinMode( PA3PIN,INPUT_PULLUP); //受信データ

  digitalWrite(PB0PIN,LOW);
  digitalWrite(PB1PIN,LOW);
  digitalWrite(PB2PIN,LOW);
  digitalWrite(PB3PIN,LOW);
  digitalWrite(PB4PIN,LOW);
  digitalWrite(PB5PIN,LOW);
  digitalWrite(PB6PIN,LOW);
  digitalWrite(PB7PIN,LOW);
  digitalWrite(FLGPIN,LOW);

  delay(500);

//SETSコマンドでSAVE用ファイル名を指定なくSAVEされた場合のデフォルトファイル名を設定
  strcpy(w_name,"default.cas");

  sdinit();
}

//4BIT受信
byte rcv4bit(void){
//HIGHになるまでループ
  while(digitalRead(CHKPIN) != HIGH){
  }
//受信
  byte j_data = digitalRead(PA0PIN)+digitalRead(PA1PIN)*2+digitalRead(PA2PIN)*4+digitalRead(PA3PIN)*8;
//FLGをセット
  digitalWrite(FLGPIN,HIGH);
//LOWになるまでループ
  while(digitalRead(CHKPIN) == HIGH){
  }
//FLGをリセット
  digitalWrite(FLGPIN,LOW);
  return(j_data);
}

//1BYTE受信
byte rcv1byte(void){
  byte i_data = 0;
  i_data=rcv4bit()*16;
  i_data=i_data+rcv4bit();
  return(i_data);
}

//1BYTE送信
void snd1byte(byte i_data){
//下位ビットから8ビット分をセット
  digitalWrite(PB0PIN,(i_data)&0x01);
  digitalWrite(PB1PIN,(i_data>>1)&0x01);
  digitalWrite(PB2PIN,(i_data>>2)&0x01);
  digitalWrite(PB3PIN,(i_data>>3)&0x01);
  digitalWrite(PB4PIN,(i_data>>4)&0x01);
  digitalWrite(PB5PIN,(i_data>>5)&0x01);
  digitalWrite(PB6PIN,(i_data>>6)&0x01);
  digitalWrite(PB7PIN,(i_data>>7)&0x01);
  digitalWrite(FLGPIN,HIGH);
//HIGHになるまでループ
  while(digitalRead(CHKPIN) != HIGH){
  }
  digitalWrite(FLGPIN,LOW);
//LOWになるまでループ
  while(digitalRead(CHKPIN) == HIGH){
  }
}

//小文字->大文字
char upper(char c){
  if('a' <= c && c <= 'z'){
    c = c - ('a' - 'A');
  }
  return c;
}

//ファイル名の最後が「.cas」でなければ付加
void addcas(char *f_name,char *m_name){
  unsigned int lp1=0;
  while (f_name[lp1] != 0x00){
    m_name[lp1] = f_name[lp1];
    lp1++;
  }
  if (f_name[lp1-4]!='.' ||
    ( f_name[lp1-3]!='c' &&
      f_name[lp1-3]!='C' ) ||
    ( f_name[lp1-2]!='a'  &&
      f_name[lp1-3]!='A' ) ||
    ( f_name[lp1-1]!='s' &&
      f_name[lp1-1]!='S' ) ){
         m_name[lp1++] = '.';
         m_name[lp1++] = 'c';
         m_name[lp1++] = 'a';
         m_name[lp1++] = 's';
  }
  m_name[lp1] = 0x00;
}

//比較文字列取得 32+1文字まで取得、ただしダブルコーテーションは無視する
void receive_name(char *f_name){
char r_data;
  unsigned int lp2 = 0;
  for (unsigned int lp1 = 0;lp1 <= 32;lp1++){
    r_data = rcv1byte();
    if (r_data != 0x22){
      f_name[lp2] = r_data;
      lp2++;
    }
  }
}

//比較文字列取得 32+1文字まで取得し先頭の6文字をファイルネームとする、ただしダブルコーテーションは無視する
void receive_name6(char *f_name){
char r_data;
  unsigned int lp2 = 0;
  for (unsigned int lp1 = 0;lp1 <= 32;lp1++){
    r_data = rcv1byte();
    if (lp2 < 6){
      if (r_data != 0x22){
        f_name[lp2] = r_data;
        lp2++;
      }
    }else{
      f_name[lp2] = 0x00;
      lp2++;
    }
  }
}

//f_nameとc_nameをc_nameに0x00が出るまで比較
//FILENAME COMPARE
boolean f_match(char *f_name,char *c_name){
  boolean flg1 = true;
  unsigned int lp1 = 0;
  while (lp1 <=32 && c_name[0] != 0x00 && flg1 == true){
    if (upper(f_name[lp1]) != c_name[lp1]){
      flg1 = false;
    }
    lp1++;
    if (c_name[lp1]==0x00){
      break;
    }
  }
  return flg1;
}

// SD-CARDのFILELIST
void dirlist(void){
//比較文字列取得 32+1文字まで
  receive_name(c_name);
//
  File file2 = SD.open( "/" );
  if( file2 == true ){
//状態コード送信(OK)
    snd1byte(0x00);

    File entry =  file2.openNextFile();
    int cntl2 = 0;
    unsigned int br_chk =0;
    int page = 1;
//全件出力の場合には10件出力したところで一時停止、キー入力により継続、打ち切りを選択
    while (br_chk == 0) {
      if(entry){
        entry.getName(f_name,36);
        unsigned int lp1=0;
//一件送信
//比較文字列でファイルネームを先頭から比較して一致するものだけを出力
        if (f_match(f_name,c_name)){
//sdir[]にf_nameを保存
          strcpy(sdir[cntl2],f_name);
          snd1byte(0x30+cntl2);
          snd1byte(0x20);
          while (lp1<=36 && f_name[lp1]!=0x00){
          snd1byte(upper(f_name[lp1]));
          lp1++;
          }
          snd1byte(0x0D);
          snd1byte(0x00);
          cntl2++;
        }
      }
// CNTL2 > 表示件数-1
      if (!entry || cntl2 > 9){
//継続・打ち切り選択指示要求
        snd1byte(0xfe);

//選択指示受信(0:継続 B:前ページ 以外:打ち切り)
        br_chk = rcv1byte();
//前ページ処理
        if (br_chk==0x42){
//先頭ファイルへ
          file2.rewindDirectory();
//entry値更新
          entry =  file2.openNextFile();
//もう一度先頭ファイルへ
          file2.rewindDirectory();
          if(page <= 2){
//現在ページが1ページ又は2ページなら1ページ目に戻る処理
            page = 0;
          } else {
//現在ページが3ページ以降なら前々ページまでのファイルを読み飛ばす
            page = page -2;
            cntl2=0;
//page*表示件数
            while(cntl2 < page*10){
              entry =  file2.openNextFile();
              if (f_match(f_name,c_name)){
                cntl2++;
              }
            }
          }
          br_chk=0;
        }
//1～0までの数字キーが押されたらsdir[]から該当するファイル名を送信
        if(br_chk>=0x30 && br_chk<=0x39){
          file_r = SD.open( sdir[br_chk-0x30], FILE_READ );
          if( file_r == true ){
//f_length設定、r_count初期化
            f_length = file_r.size();
            r_count = 0;
            unsigned int lp2=0;
            snd1byte(0xFD);
            while (lp2<=36 && sdir[br_chk-0x30][lp2]!=0x00){
              snd1byte(upper(sdir[br_chk-0x30][lp2]));
              lp2++;
            }
            snd1byte(0x0A);
            snd1byte(0x0D);
            snd1byte(0x00);
          }
        }
        page++;
        cntl2 = 0;
      }
//ファイルがまだあるなら次読み込み、なければ打ち切り指示
      if (entry){
        entry =  file2.openNextFile();
      }else{
        br_chk=1;
      }
    }
//処理終了指示
    snd1byte(0xFF);
    snd1byte(0x00);
  }else{
    snd1byte(0xf1);
  }
}

// LOADFILEOPEN 読み込み用のファイル名を設定する
void loadopen(void){
  boolean flg = false;
//DOSファイル名取得
  receive_name(m_name);
  addcas(m_name,f_name);
//ファイルが存在しなければERROR
  if (SD.exists(f_name) == true){
//ファイルオープン
    file_r = SD.open( f_name, FILE_READ );

    if( true == file_r ){
//f_length設定、r_count初期化
      f_length = file_r.size();
      r_count = 0;
//状態コード送信(OK)
      snd1byte(0x00);
      flg = true;
    } else {
      snd1byte(0xf2);
      sdinit();
      flg = false;
    }
  }else{
    snd1byte(0xf1);
    sdinit();
    flg = false;
  }
}

// SAVEFILEOPEN 書き込み用のファイル名を設定する
void saveopen(void){
  boolean flg = false;
//DOSファイル名取得
  receive_name(m_name);
  addcas(m_name,f_name);
  strcpy(w_name,f_name);
//ファイルオープン
  if(file_w==true){
    file_w.close();
  }
  file_w = SD.open( w_name, FILE_WRITE );
//状態コード送信(OK)
  snd1byte(0x00);
}

// sloadコマンド
void sload(void){
  boolean flg = false;
  int wk1 =0;
  unsigned char rdata;
  unsigned int lp1 =0;
//比較文字列取得 32+1文字まで
  receive_name6(c_name);
  if (file_r == true){
    snd1byte(0x00);
//0xd3が10個連続するまで読み飛ばし、読み飛ばしでファイルエンドになってしまったらエラー終了
    while (flg == false && f_length >= r_count){
      rdata=file_r.read();
      r_count++;
      if (rdata == 0xd3){
          wk1++;
        } else{
          wk1=0;
      }
      if (wk1 >= 10 ){
        flg = true;
      }
//ファイルネームが指定された場合、読み出したファイルネームが一致するまで読み飛ばし
      if (flg == true){
        for(lp1=0; lp1 <= 5;lp1++){
          f_name[lp1]=file_r.read();
          r_count++;
        }
        f_name[6]=0x00;
        if (c_name[0]!=0x00){
          if (f_match(f_name,c_name) == false){
            flg = false;
          }
        }
      }
    }
    if(flg == true){
      snd1byte(0x00);
//ファイルネームを送信
      for(lp1=0; lp1 <= 5;lp1++){
        snd1byte(f_name[lp1]);
      }
//ヘッダを読み飛ばし
      for(lp1=1; lp1 <= 8;lp1++){
        rdata=file_r.read();
        r_count++;
      }
//次行アドレスポインタから1行Byte数を計算し送信、1行Byte数分の実データも読み出して送信
      s_adrs2=file_r.read();
      r_count++;
      s_adrs1=file_r.read();
      r_count++;
      e_adrs = s_adrs1*256+s_adrs2;
      if (e_adrs != 0){
        wk1=s_adrs2-3;
        snd1byte(wk1);
        s_adrs =e_adrs;
        for (lp1=1;lp1 <= wk1;lp1++){
          rdata=file_r.read();
          r_count++;
          snd1byte(rdata);
        }
      }
//2行目以降処理
//次行アドレスポインタから1行Byte数を計算し送信、1行Byte数分の実データも読み出して送信
      while (e_adrs != 0){
        s_adrs2=file_r.read();
        r_count++;
        s_adrs1=file_r.read();
        r_count++;
        e_adrs = s_adrs1*256+s_adrs2;
        if (e_adrs != 0){
          wk1 = e_adrs-s_adrs-2;
          s_adrs =e_adrs;
          snd1byte(wk1);
          for (lp1=1;lp1 <= wk1;lp1++){
            rdata=file_r.read();
            r_count++;
            snd1byte(rdata);
          }
        }
      }
      snd1byte(0x00);
    } else{
      snd1byte(0xf1);
      sdinit();
      r_count = 0;
    }
  } else{
    snd1byte(0xf1);
    sdinit();
    r_count = 0;
  }
}

// sbloadコマンド
void sbload(void){
  boolean flg = false;
  int wk1 =0;
  unsigned char rdata;
  unsigned int lp1 =0;
//比較文字列取得 32+1文字まで
  receive_name6(c_name);
  if (file_r == true){
    snd1byte(0x00);
//0xd0を10個連続するまで読み飛ばし、読み飛ばしでファイルエンドになってしまったらエラー終了
    while (flg == false && f_length >= r_count){
      rdata=file_r.read();
      r_count++;
      if (rdata == 0xd0){
          wk1++;
        } else{
          wk1=0;
      }
      if (wk1 >= 10 ){
        flg = true;
      }
//ファイルネームが指定された場合、読み出したファイルネームが一致するまで読み飛ばし
      if (flg == true){
        for(lp1=0; lp1 <= 5;lp1++){
          f_name[lp1]=file_r.read();
          r_count++;
        }
        f_name[6]=0x00;
        if (c_name[0]!=0x00){
          if (f_match(f_name,c_name) == false){
            flg = false;
          }
        }
      }
    }
    if(flg == true){
      snd1byte(0x00);
//ファイルネームを送信
      for(lp1=0; lp1 <= 5;lp1++){
        snd1byte(f_name[lp1]);
      }
//ヘッダを読み飛ばし
      for(lp1=1; lp1 <= 8;lp1++){
        rdata=file_r.read();
        r_count++;
      }
//スタートアドレスを読み出して送信
      s_adrs2=file_r.read();
      r_count++;
      s_adrs1=file_r.read();
      r_count++;
      s_adrs = s_adrs1*256+s_adrs2;
      snd1byte(s_adrs2);
      snd1byte(s_adrs1);
//エンドアドレスを読み出して送信
      s_adrs2=file_r.read();
      r_count++;
      s_adrs1=file_r.read();
      r_count++;
      e_adrs = s_adrs1*256+s_adrs2;
      snd1byte(s_adrs2);
      snd1byte(s_adrs1);
//実行アドレスを読み出して送信
      s_adrs2=file_r.read();
      r_count++;
      s_adrs1=file_r.read();
      r_count++;
      g_adrs = s_adrs1*256+s_adrs2;
      snd1byte(s_adrs2);
      snd1byte(s_adrs1);
//スタートアドレスからエンドアドレスまでのデータを読み出して送信
      for(lp1=s_adrs; lp1 <= e_adrs;lp1++){
        rdata=file_r.read();
        snd1byte(rdata);
        r_count++;
      }
    } else{
      snd1byte(0xf1);
      sdinit();
      r_count = 0;
    }
  } else{
    snd1byte(0xf1);
    sdinit();
    r_count = 0;
  }
}

//ヘッダ書き込み
void header_write(void){
        file_w.write(char(0x1f));
        file_w.write(char(0xa6));
        file_w.write(char(0xde));
        file_w.write(char(0xba));
        file_w.write(char(0xcc));
        file_w.write(char(0x13));
        file_w.write(char(0x7d));
        file_w.write(char(0x74));
}

//ファイルヘッダ書き込み
void file_header(char hdata){
  unsigned int lp1 =0;
//ロングヘッダ書き込み
  header_write();
//hdata x 10
  for(lp1=1; lp1 <= 10;lp1++){
    file_w.write(hdata);
  }
//ファイルネーム送信及び書き込み
  for(lp1=0; lp1 <= 5;lp1++){
    snd1byte(c_name[lp1]);
    file_w.write(c_name[lp1]);
  }
//ショートヘッダ書き込み
      header_write();
}

// ssaveコマンド
void ssave(void){
  boolean flg = false;
  unsigned int wk1 =0;
  unsigned char rdata;
  unsigned int lp1 =0;
//比較文字列取得 32+1文字まで
  receive_name6(c_name);
//ファイルネームが指定されていなければエラー
  if (c_name[0] != 0x00){
//w_nameでファイルオープン
    if(file_w==true){
      file_w.close();
    }
    file_w = SD.open( w_name, FILE_WRITE );
    if(file_w==true){
      snd1byte(0x00);
//ファイルヘッダ書き込み
      file_header(char(0xd3));
      wk1=rcv1byte();
//1行Byte数が0になるまでループ
      while(wk1!=0){
//次行プログラムポインタを受信して書き込み
        rdata=rcv1byte();
        file_w.write(rdata);
        rdata=rcv1byte();
        file_w.write(rdata);
//1行分のデータを受信して書き込み
          for(lp1=1; lp1 <= wk1;lp1++){
            rdata=rcv1byte();
            file_w.write(rdata);
          }
        wk1=rcv1byte();
      }
//終了マークを書き込み
      for(lp1=1; lp1 <= 12;lp1++){
        file_w.write(char(0x00));
      }
      file_w.close();
      snd1byte(0x00);
    }else{
      snd1byte(0xf1);
      sdinit();
    }
  }else{
    snd1byte(0xf1);
    sdinit();
  }
}  

// sbsaveコマンド
void sbsave(void){
  boolean flg = false;
  unsigned int wk1 =0;
  unsigned char rdata;
  unsigned int lp1 =0;
//比較文字列取得 32+1文字まで
  receive_name6(c_name);
//パラメータ正常フラグが送られてきたら処理継続
  rdata = rcv1byte();
  if (rdata == 0x00){
//ファイルネームが指定されていなければエラー終了
    if (c_name[0] != 0x00){
//w_nameでファイルオープン
      if(file_w==true){
        file_w.close();
      }
      file_w = SD.open( w_name, FILE_WRITE );
      if(file_w==true){
        snd1byte(0x00);
//ファイルヘッダ書き込み
      file_header(char(0xd0));
//スタートアドレス受信及び書き込み
        s_adrs1=rcv1byte();
        file_w.write(s_adrs1);
        s_adrs2=rcv1byte();
        file_w.write(s_adrs2);
        s_adrs = s_adrs2*256+s_adrs1;
//エンドアドレス受信及び書き込み
        s_adrs1=rcv1byte();
        file_w.write(s_adrs1);
        s_adrs2=rcv1byte();
        file_w.write(s_adrs2);
        e_adrs = s_adrs2*256+s_adrs1;
//実行アドレス受信及び書き込み
        s_adrs1=rcv1byte();
        file_w.write(s_adrs1);
        s_adrs2=rcv1byte();
        file_w.write(s_adrs2);
        g_adrs = s_adrs2*256+s_adrs1;
//スタートアドレスからエンドアドレスまでのデータを受信して書き込み
        for(lp1=0; lp1 <= (e_adrs-s_adrs);lp1++){
          rdata=rcv1byte();
          file_w.write(rdata);
        }
        file_w.close();
        snd1byte(0x00);
      }else{
        snd1byte(0xf1);
        sdinit();
      }
    }else{
      snd1byte(0xf1);
      sdinit();
    }
  }
}

void loop()
{
  digitalWrite(PB0PIN,LOW);
  digitalWrite(PB1PIN,LOW);
  digitalWrite(PB2PIN,LOW);
  digitalWrite(PB3PIN,LOW);
  digitalWrite(PB4PIN,LOW);
  digitalWrite(PB5PIN,LOW);
  digitalWrite(PB6PIN,LOW);
  digitalWrite(PB7PIN,LOW);
  digitalWrite(FLGPIN,LOW);
//コマンド取得待ち
////    Serial.println("COMMAND WAIT");
  byte cmd = rcv1byte();
////    Serial.println(cmd,HEX);
  if (eflg == false){
    switch(cmd) {
//41hでファイルリスト出力
      case 0x41:
////    Serial.println("FILE LIST START");
//状態コード送信(OK)
        snd1byte(0x00);
        sdinit();
        dirlist();
        break;
//42hでLOADFILEOPEN
      case 0x42:
////    Serial.println("LOADFILEOPEN");
//状態コード送信(OK)
        snd1byte(0x00);
        loadopen();
        break;
//43hでSAVEFILEOPEN
      case 0x43:
////    Serial.println("SAVEFILEOPEN");
//状態コード送信(OK)
        snd1byte(0x00);
        saveopen();
        break;
//44h:sload
      case 0x44:
////    Serial.println("sload START");
//状態コード送信(OK)
        snd1byte(0x00);
        sload();
////  delay(1500);
        break;
//45h:sbload
      case 0x45:
////    Serial.println("sbload START");
//状態コード送信(OK)
        snd1byte(0x00);
        sbload();
////  delay(1500);
        break;
//46h:ssave
      case 0x46:
////    Serial.println("ssave START");
//状態コード送信(OK)
        snd1byte(0x00);
        ssave();
////  delay(1500);
        break;
//47h:sbload
      case 0x47:
////    Serial.println("sbsave START");
//状態コード送信(OK)
        snd1byte(0x00);
        sbsave();
////  delay(1500);
        break;
      default:
//状態コード送信(CMD ERROR)
        snd1byte(0xF4);
    }
  } else {
//状態コード送信(ERROR)
    snd1byte(0xF0);
    sdinit();
  }
}
